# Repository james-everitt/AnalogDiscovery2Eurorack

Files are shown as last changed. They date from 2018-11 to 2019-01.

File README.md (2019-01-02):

# AnalogDiscovery2Eurorack
Breakout board for the Digilent Analog Discovery 2 for Eurorack module testing and calibration

SSW-115-02-G-D-RA header just fits into the Analog Discovery 2, mine was a tight fit

Voltage rails and Digital I/O pins are passed through to the far header

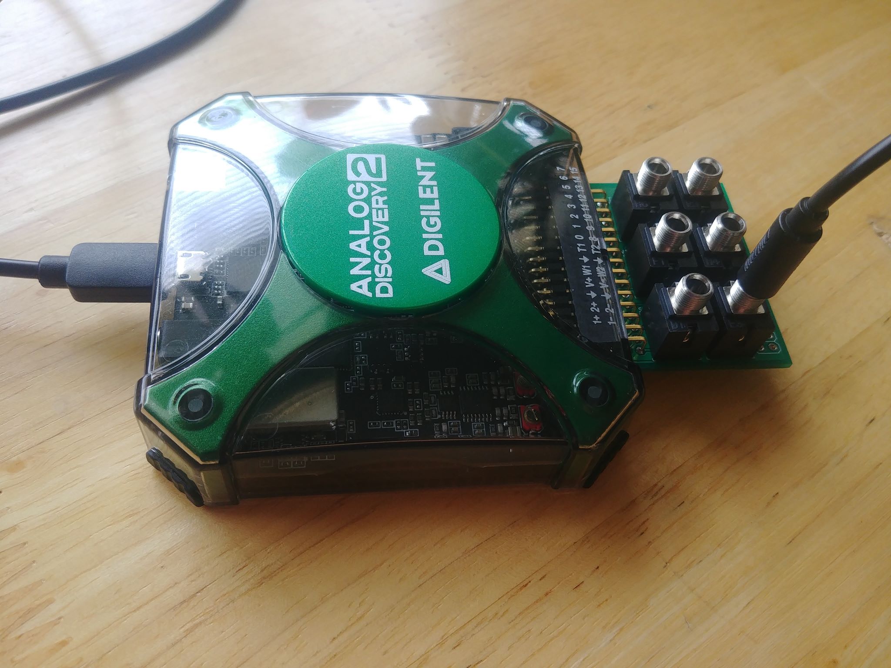
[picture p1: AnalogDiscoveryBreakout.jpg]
Title


# Crosstalk measurements
Initally I thought my breakout had bad high frequency performance; using the AD Bode plot function I measured crosstalk at ~-48dB from 5kHz upward. However doing the same measurement with the BNC adaptor board that Digilent offer, I measured -38dB of crosstalk in this same region! Make sense as I used a ground flood fill wherever possible, and the BNC board from digilent doesnt.

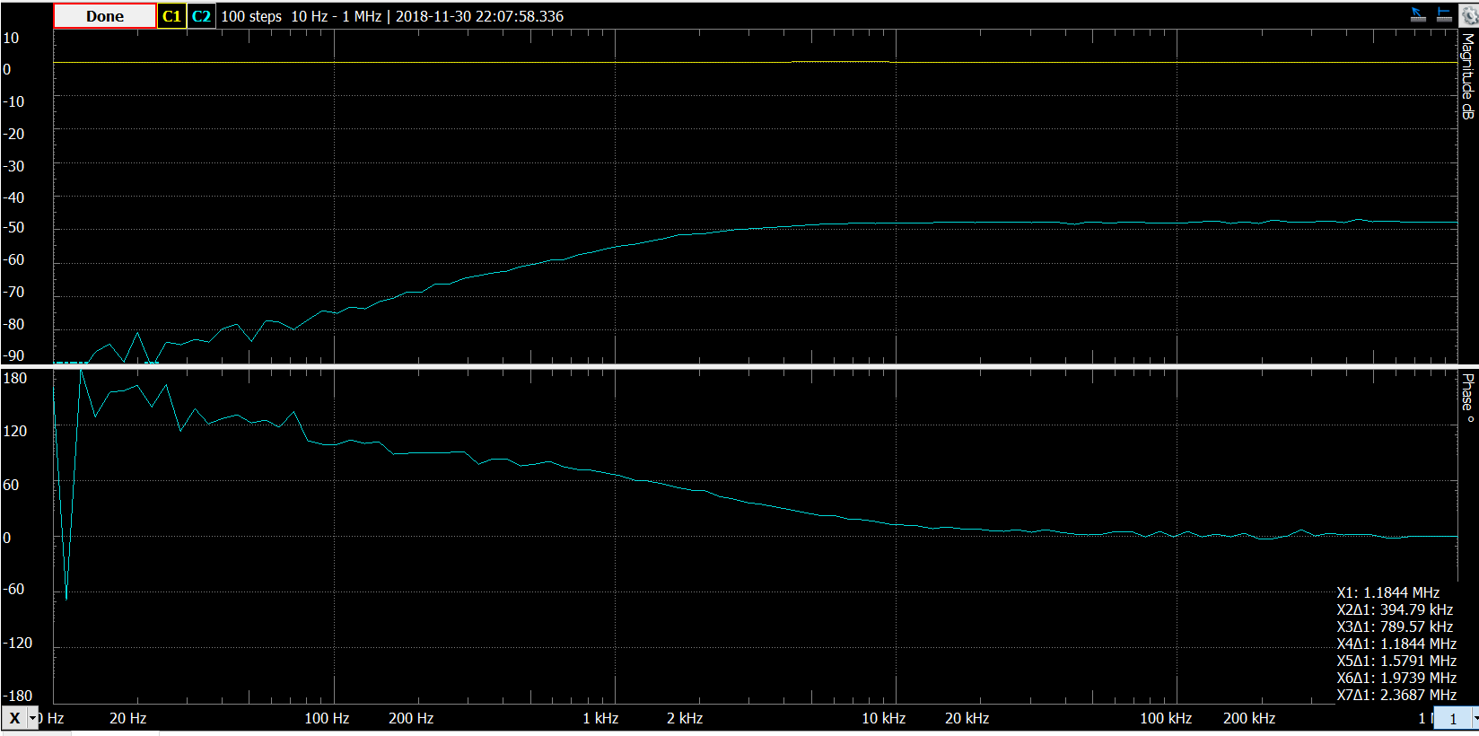
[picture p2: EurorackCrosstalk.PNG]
Eurorack measurement

Eurorack adaptor crosstalk
<br>

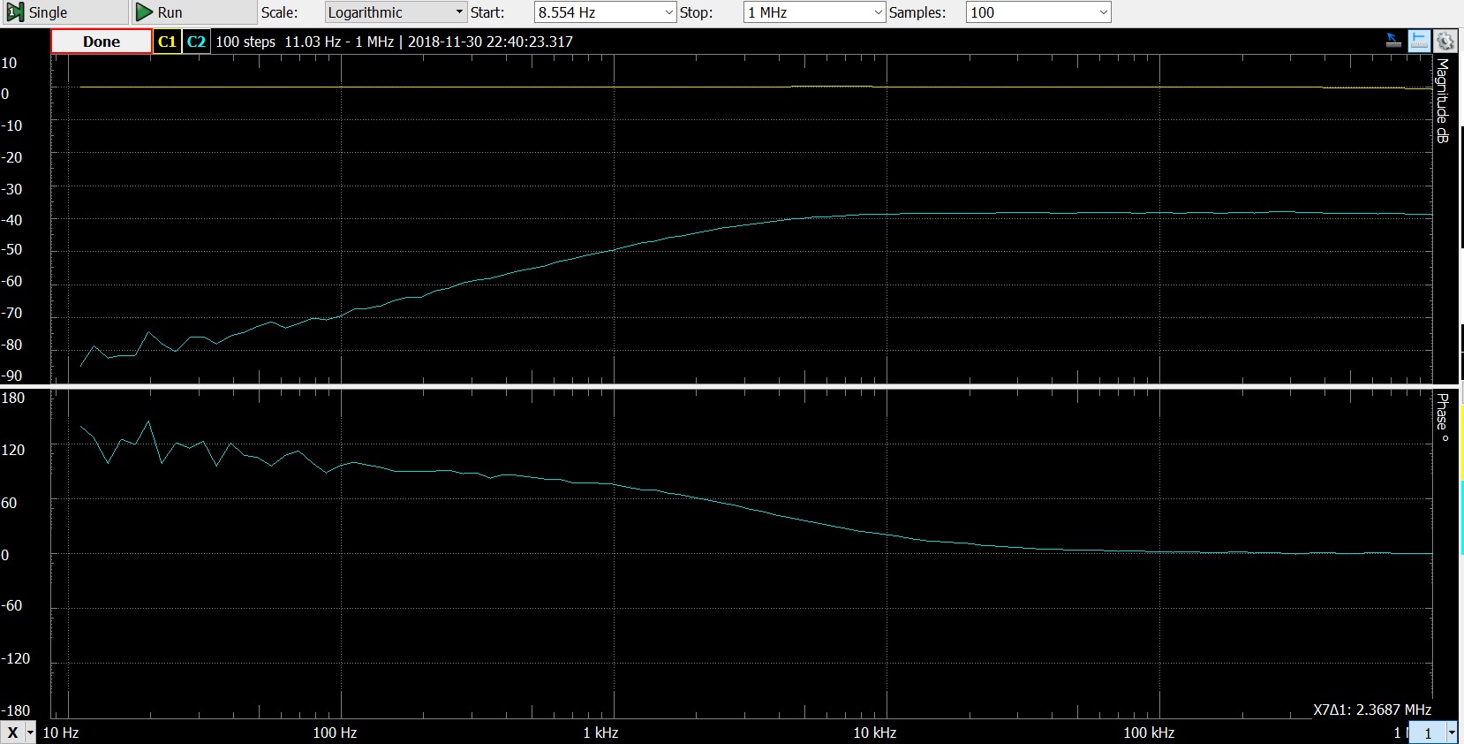
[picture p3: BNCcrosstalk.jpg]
BNC measurement

Official BNC adaptor crosstalk

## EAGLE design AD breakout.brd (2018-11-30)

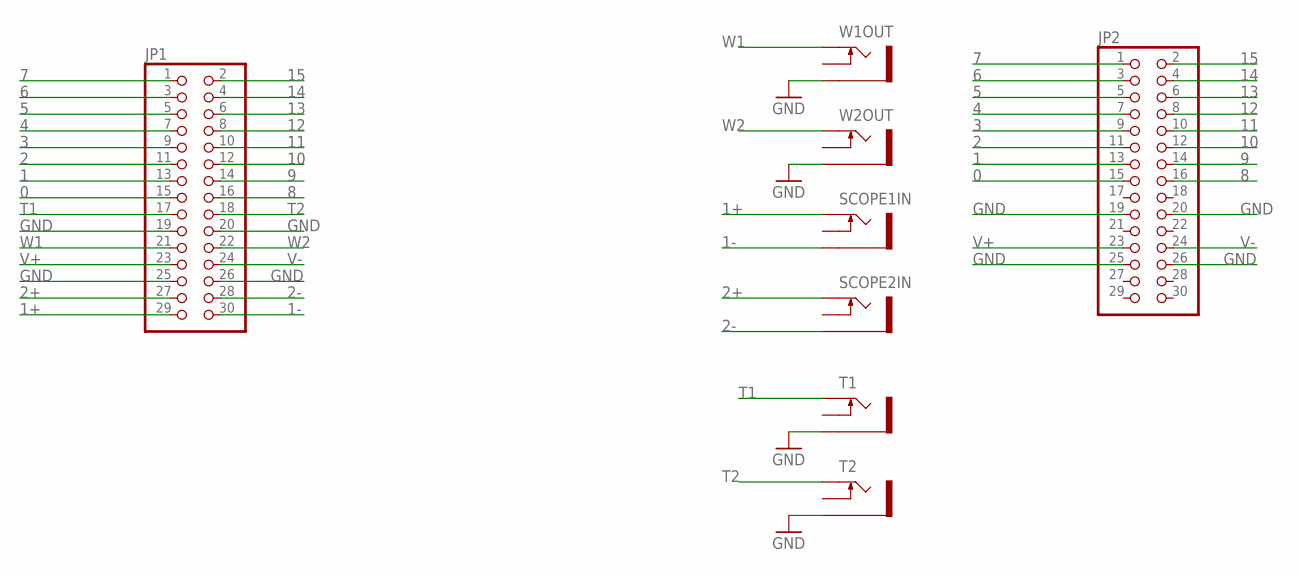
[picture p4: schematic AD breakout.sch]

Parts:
JP1, JP2: PINHD-2X15; 2X15
SCOPE1IN, SCOPE2IN: THONKICONNNEW; WQP-PJ301M-12_JACK
T1, T2: THONKICONNNEW; WQP-PJ301M-12_JACK
W1OUT, W2OUT: THONKICONNNEW; WQP-PJ301M-12_JACK

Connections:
0: JP1.15, JP2.15
1: JP1.13, JP2.13
1+: JP1.29, SCOPE1IN.P$1_TIP (TIP)
1-: JP1.30, SCOPE1IN.P$3_SLEEVE (SLEEVE)
2: JP1.11, JP2.11
2+: JP1.27, SCOPE2IN.P$1_TIP (TIP)
2-: JP1.28, SCOPE2IN.P$3_SLEEVE (SLEEVE)
3: JP1.9, JP2.9
4: JP1.7, JP2.7
5: JP1.5, JP2.5
6: JP1.3, JP2.3
7: JP1.1, JP2.1
8: JP1.16, JP2.16
9: JP1.14, JP2.14
10: JP1.12, JP2.12
11: JP1.10, JP2.10
12: JP1.8, JP2.8
13: JP1.6, JP2.6
14: JP1.4, JP2.4
15: JP1.2, JP2.2
GND: JP1.19, JP1.20, JP1.25, JP1.26, JP2.19, JP2.20, JP2.25, JP2.26, T1.P$3_SLEEVE (SLEEVE), T2.P$3_SLEEVE (SLEEVE), W1OUT.P$3_SLEEVE (SLEEVE), W2OUT.P$3_SLEEVE (SLEEVE)
T1: JP1.17, T1.P$1_TIP (TIP)
T2: JP1.18, T2.P$1_TIP (TIP)
V+: JP1.23, JP2.23
V-: JP1.24, JP2.24
W1: JP1.21, W1OUT.P$1_TIP (TIP)
W2: JP1.22, W2OUT.P$1_TIP (TIP)

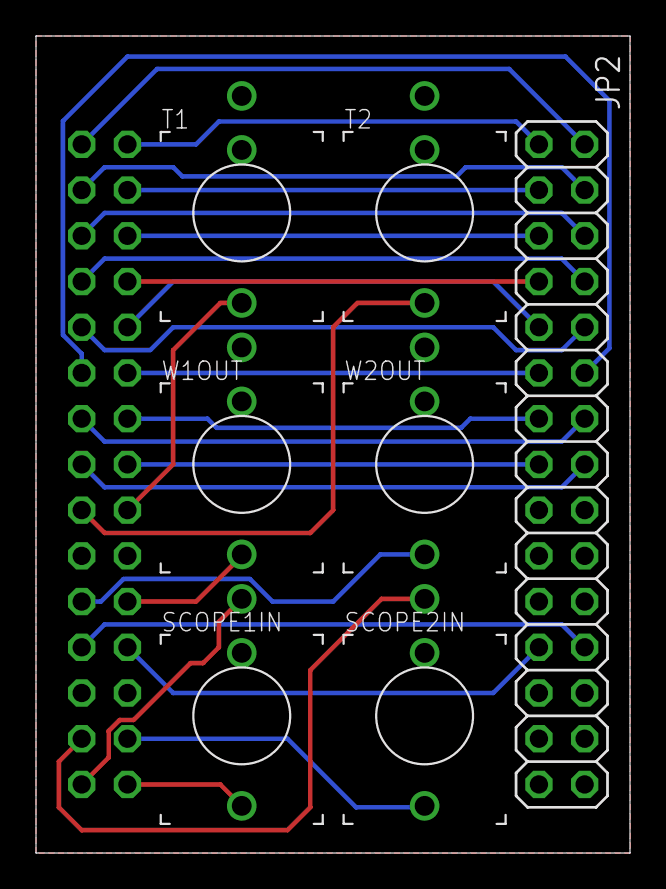
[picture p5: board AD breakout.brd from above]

Board: 2 copper layers, 33.0 x 45.4 mm, 8 parts (1 on the bottom side), 27 nets.
